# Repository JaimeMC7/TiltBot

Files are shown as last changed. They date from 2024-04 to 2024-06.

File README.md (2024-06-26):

# TiltBot
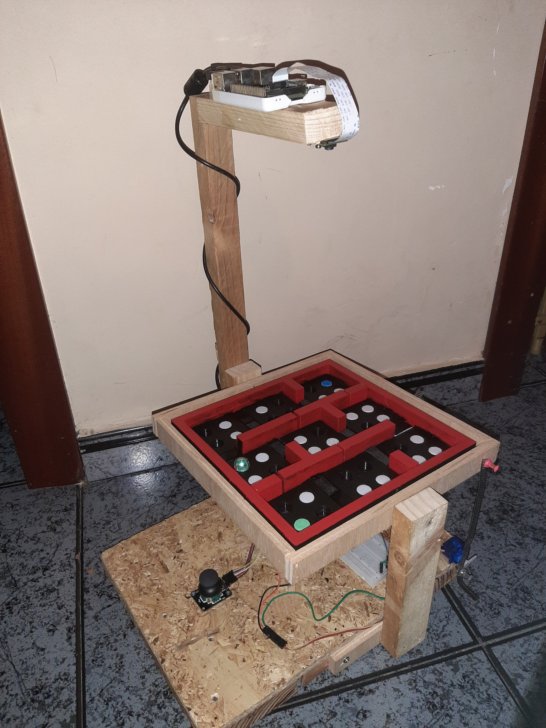
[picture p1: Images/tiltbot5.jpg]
TiltBot-image


# Authors
- David Fuentes Insa
- Sergio López Parejo
- Robert Pearson Ruiz
- Jaime Martínez Coca

## Index
- [Project description](#Project-description)
- [Structure](#Structure)
  - [Labyrinth platform](#Labyrinth-platform)
  - [Walls and plugs](#Walls-and-plugs)
- [Arquitecture](#Arquitecture)
  - [Action Module](#Action-Module)
    - [Action Hardware](#Action-Hardware)
    - [Action Software](#Action-Software)
  - [Vision Module](#Vision-Module)
    - [Vision Hardware](#Vision-Hardware)
    - [Vision Software](#Vision-Software)
    - [Limitations](#Vision-Limitations)
- [TO DOs](#TO-DOs)
- [References](#References)

## Project description
TiltBot is an entertainment device where you try to get a ball from one side of a maze to the opposite side, just by tilting it. Along the way, you'll need to dodge holes, or you'll have to start over!
Using it is simple: you can tilt the maze platform where the ball is located with a joystick.

If crossing the maze is too difficult, TiltBot has an extra feature. You can switch to an automatic mode, where AI will solve the maze, showing you one of the possible paths to the end. (For now, the algorithm is somewhat limited. See the Limitations section.)

Additionally, to increase the amount of fun, the maze format can be customized. You can open or close holes, as well as restructure the walls to choose your own difficulty.

## Structure
The structure is one of the most important parts of this project. To create a customizable maze, we had to come up with a structure that would allow us to rearrange where the walls that delimit the path of the maze should be, and the holes through which it should avoid falling. We designed the platform of our maze with holes where different pieces of walls fit and holes where plugs fit that allow the ball to pass over it. In addition to this, the structure has an exterior frame that will allow the platform to rotate on an axis. This has been achieved by means of a servomotor that will be attached to this frame by means of an elongated metal plate. As for the movement in the other axis of the inner platform, we have placed another servo attached to the bottom of the inner platform of the maze and joined to the outer frame by another plate. This allows us to obtain the desired movement in both axes.

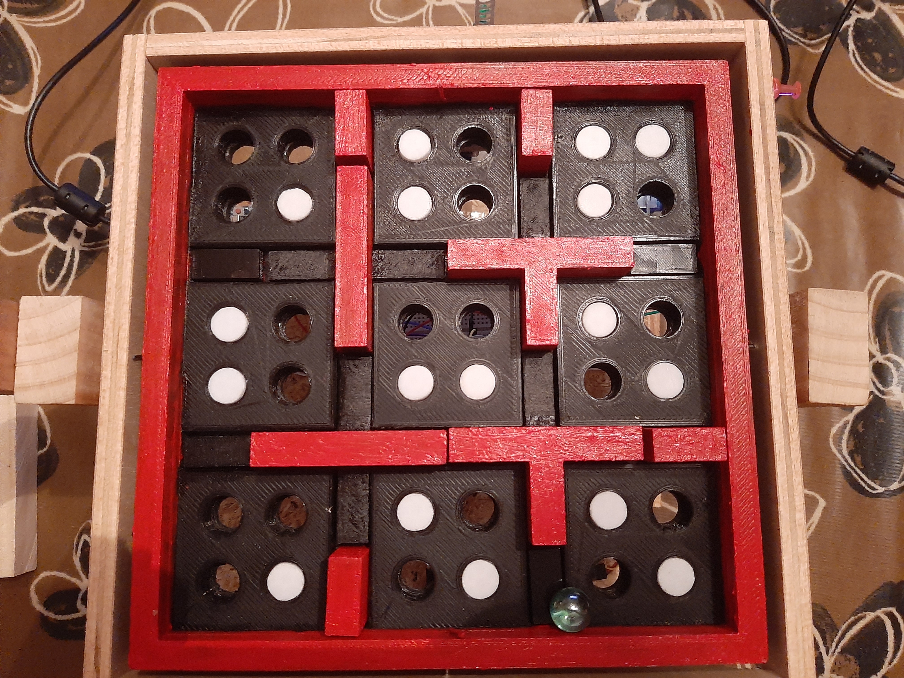
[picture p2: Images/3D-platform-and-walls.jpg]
3D-platform-and-walls


#### Labyrinth platform
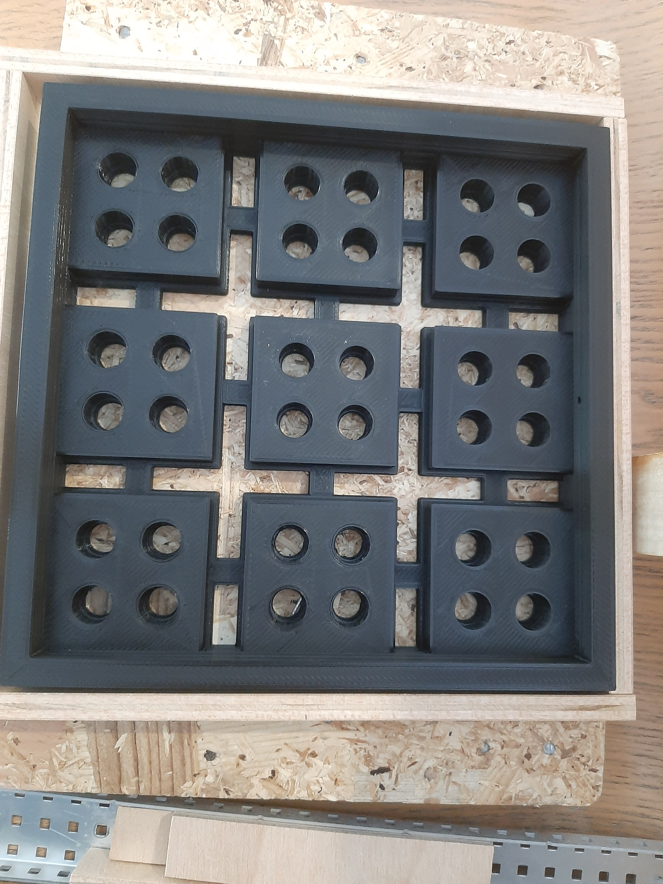
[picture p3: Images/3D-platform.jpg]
3D-platform

We made a platform that has nine main isles of floor. Among them, four central X-shaped holes remain in the center of the platform, and eight small holes are located on the exterior side. Also, each piece of the floor has four holes in it, that can be fitted with our plugs in order to make the maze either easier or harder.

#### Walls and plugs
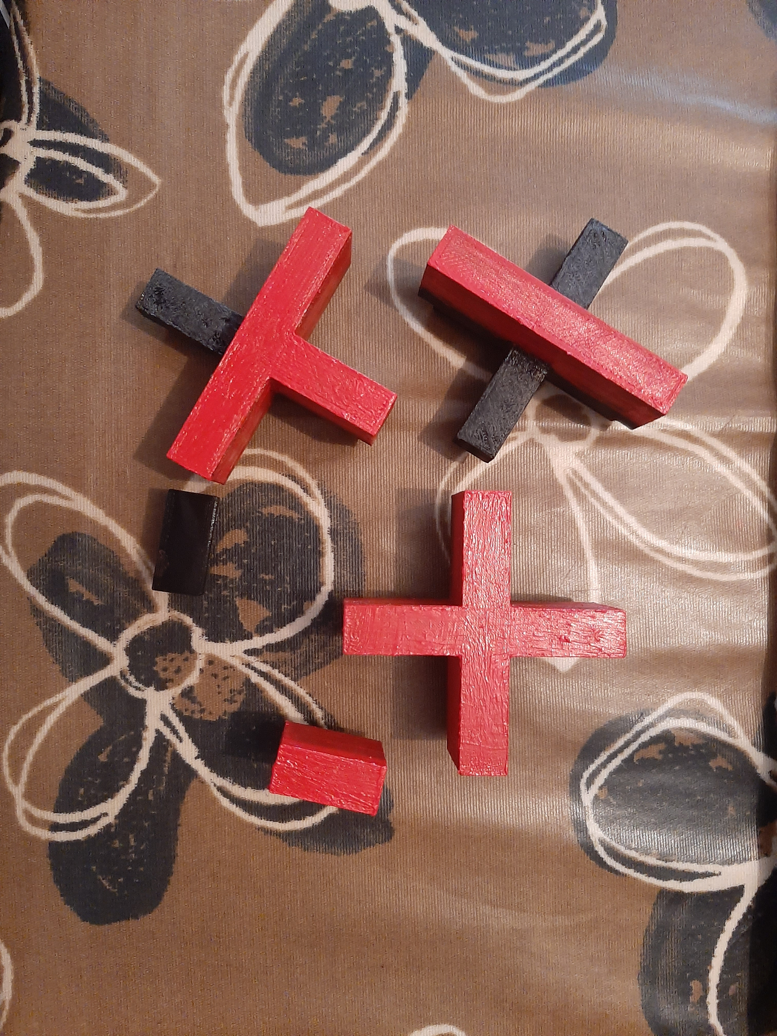
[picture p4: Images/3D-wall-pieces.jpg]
3D-wall-pieces

We have designed different types of central walls, combining parts at ground level that let us create very varied mazes. For the exterior walls, we only have two types, ground level and wall lavel. Regarding the plugs, they are all the same, and they are of such a height that allows the ball to pass over it effortlessly.

#### 

## Arquitecture
For the operation of TiltBot, we have divided its components into two interconnected modules.

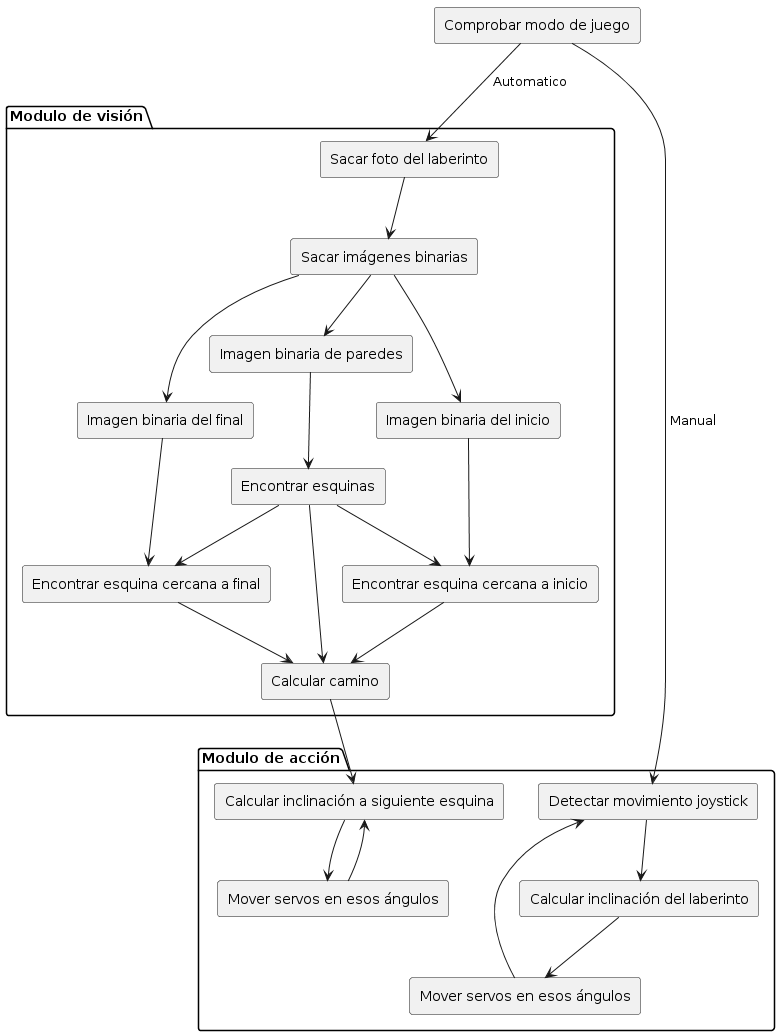
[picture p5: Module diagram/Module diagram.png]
Action-module-HW-components


### Action Module
This module is the one in charge of the actual movement of the labyrinth that allows the puzzle to be solved.

#### Action Hardware
In order to move the structure, we make use of two different servo motors, one for the outer layer, and the other for the inner layer. Each of this servos move in different directions, allowing the structure to tilt in any angle needed. For a deeper understanding check [Structure](#Structure).

To be able to control manually this servos we have also connected a joystick, which moves both motors acordingly to the direction and amount of preassure applied on it.

All of this is interconected by an Arduino UNO R3 module.

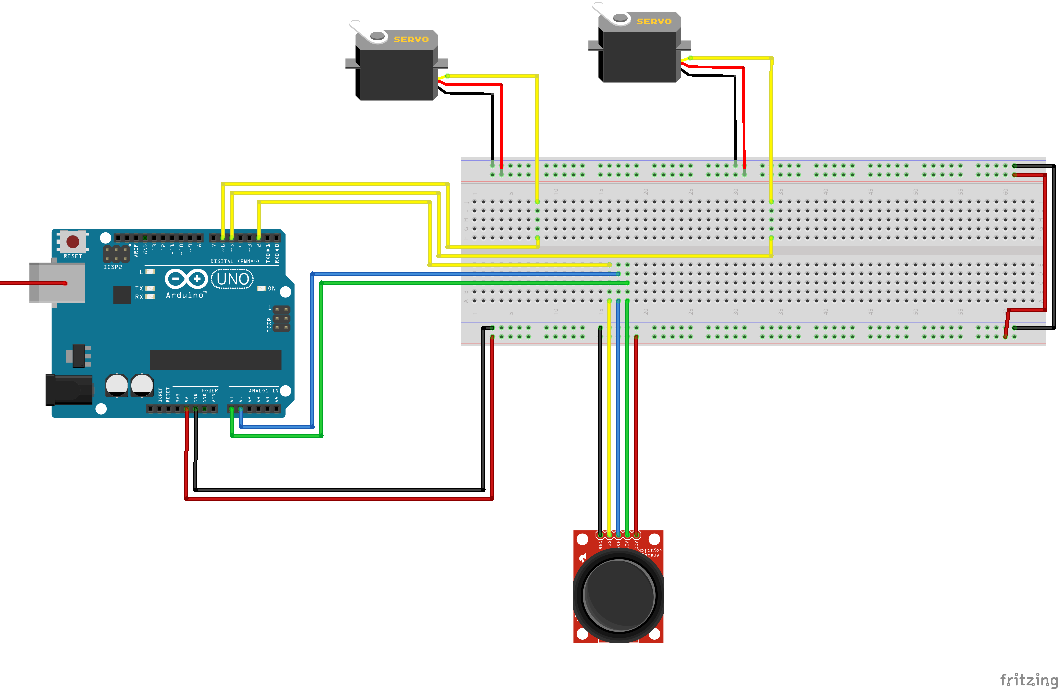
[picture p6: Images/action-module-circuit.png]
Action-module-HW-components


#### Action Software
To make the servo motors move, we have implemented some simple code in the Arduino.
This require the following libraries:
- Servo.h
- Keyboard.h
- ArduinoJson.h

The code workflow is:

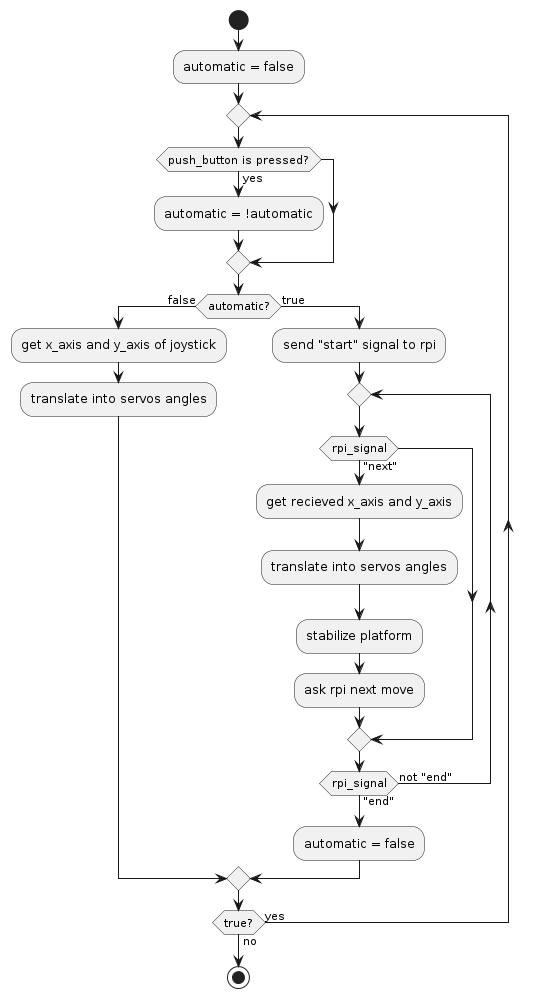
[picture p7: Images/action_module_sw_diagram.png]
action_module_sw_diagram


### Vision Module
The vision module is responsible for the automated maze-solving part. When requested, it will take a photograph of the maze from above and find a path from a starting point to an endpoint. It will then give instructions to the action module to try to move the ball along the path.

#### Vision Hardware
The hardware part is very simple. It consists of a Raspberry Pi 3B+ connected to a camera positioned above the center of the maze, and also connected to an Arduino UNO R3.

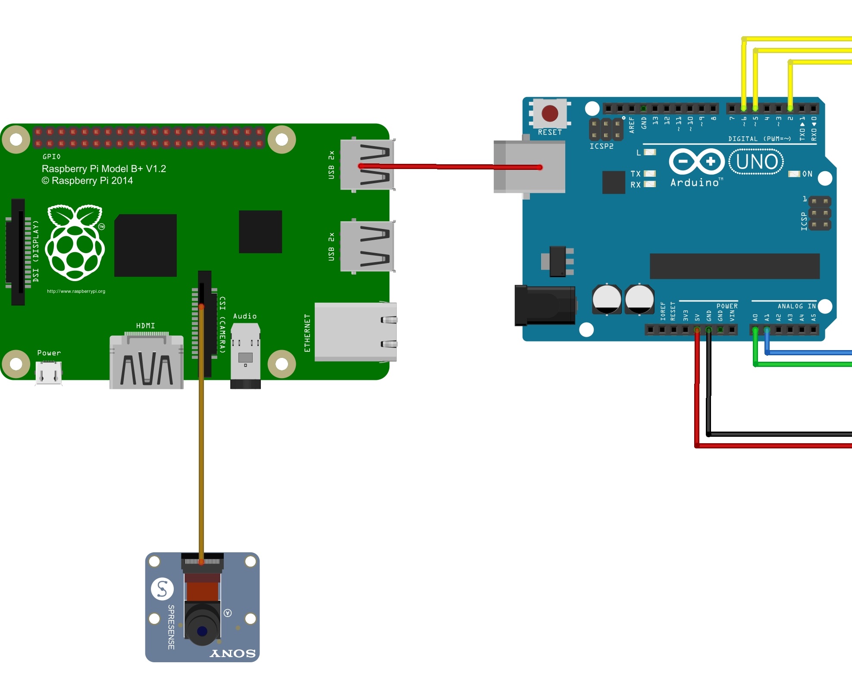
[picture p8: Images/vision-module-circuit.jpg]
Raspberry-and-cam


#### Vision Software
The software part is more complex.

*Dependencies*

To work with images, we use the OpenCV library and Numpy to handle the structures. 
Then, for the connection between the Raspberry Pi and the Arduino, we use the serial library along with the json library for sending information.

*Installation*

- pip install opencv
- pip install numpy
- pip install pyserial
- pip install json

The code waits for a start signal from the Arduino to begin the resolution algorithm. When it receives the signal, it takes a photograph of the maze, detects the walls, the starting point, and the ending point, and searches for a possible path that follows the walls.

<p>initial labyrinth photo</p>
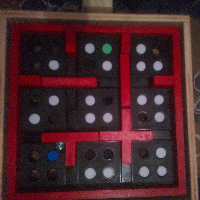
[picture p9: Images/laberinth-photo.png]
initial laberinth photo


<p>labyrinth separated by colors</p>
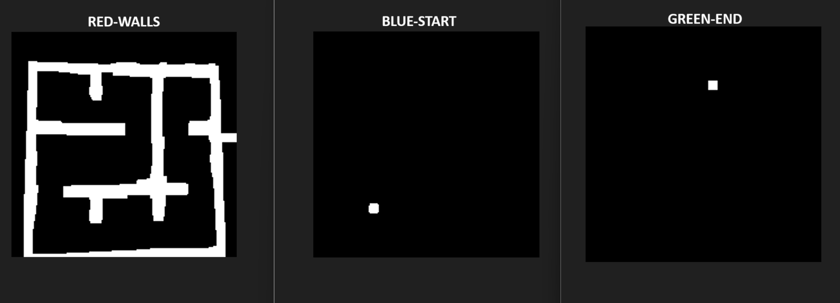
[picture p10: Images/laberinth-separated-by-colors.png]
color separation


<p>final labyrinth path</p>
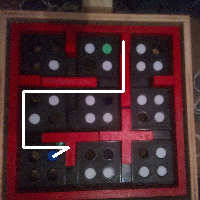
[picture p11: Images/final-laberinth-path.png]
final laberinth path


This path is calculated considering that when the maze is tilted, the ball will move to the nearest wall in that direction.

#### Vision Limitations
The pathfinding algorithm uses the walls to move the ball to the end. For this reason, there are some maze layouts that it is unable to solve, which are those where there is no way to access the final area through the walls. An example it cannot solve is the following.

The rest of the cases work correctly, at least on perfect images.

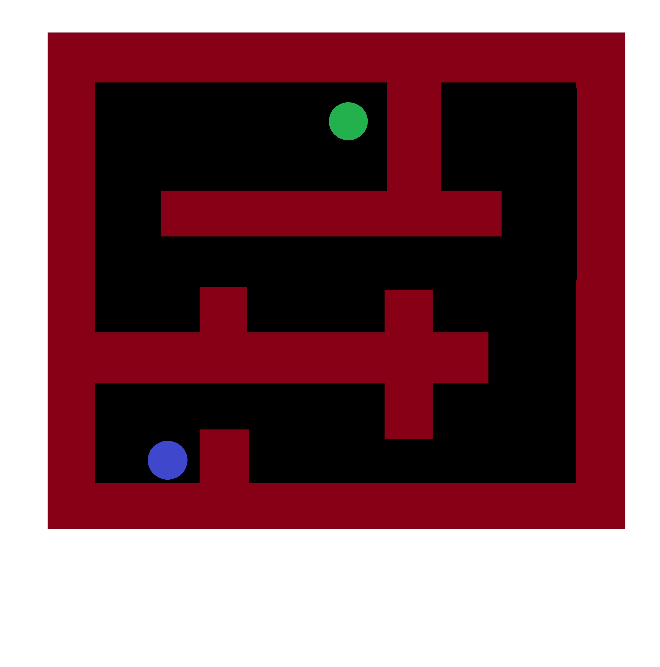
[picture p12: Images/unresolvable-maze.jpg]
Unresolvable maze


However, when applying the algorithm to real images, it does not work in 100% of the cases. Through testing, we have concluded that this is due to, among other things, imperfections in the materials/structure.

## TO DOs
- [x] Design and assembly of the structure.
- [x] Calibrate the movement ranges of the platform's servomotors.
  - [x] In the code.
  - [x] Phisically.
- [x] Vision Module.
  - [x] Differentiate obstacles, ball, and maze path using a camera.
  - [x] Basic algorithm to solve the maze.
  - [x] Improve the solving algorithm.
  - [x] Calibrate commands to move the ball in the correct direction.
- [x] Communication between the vision module and the action module.

## References
- Original idea for the project by Antonio Álvarez: https://www.youtube.com/watch?v=PMSr5L0SD24
- Tutorial - Usage of Joysticks with Arduino: https://programarfacil.com/blog/arduino-blog/joystick-con-arduino/
- Tutorial - Usage of Servos with Arduino: https://programarfacil.com/blog/arduino-blog/servomotor-con-arduino/
- Tutorial - Send data from Arduino to Raspberry (Serial connection): https://www.youtube.com/watch?v=-3swby4ryU4

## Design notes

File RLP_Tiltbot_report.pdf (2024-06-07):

RPL - Computer Engineering. UAB (Barcelona) 2023-2024

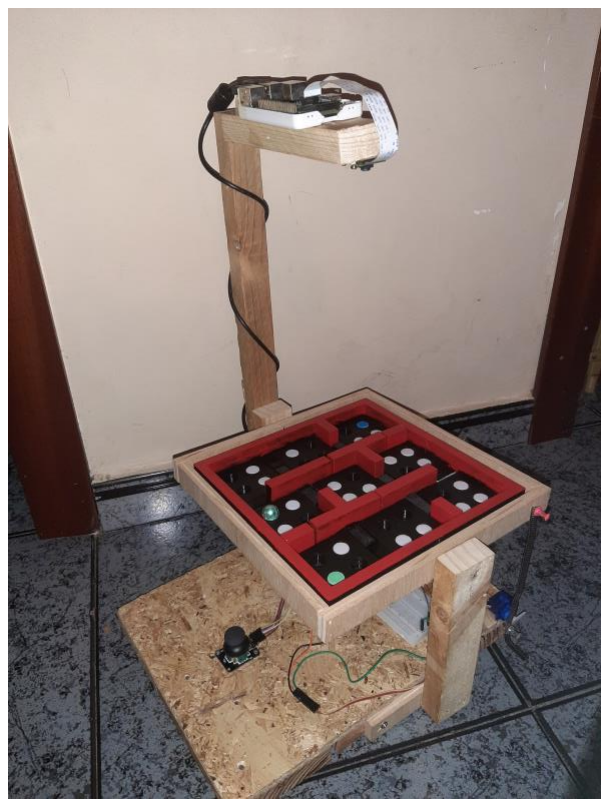
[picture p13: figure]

# TiltBot

Interactive maze-solving entertainment device.

FINAL SPRINT
DATE: 12 June 2024

Jaime Martinez Coca - 1634495 Robert Pearson Ruiz - 1630916 Sergio López Parejo - 1634093 David Fuentes Insa - 1637892

TiltBot

# Table of Contents

Final Sprint
Date: 12 June 2024
TiltBot | 1

# TiltBot

Interactive maze-solving entertainment device.

### Project description

TiltBot is an entertainment device where you try to get a ball from one side of a maze to the opposite side, just by tilting it. Along the way, you'll need to dodge holes, or you'll have to start over! Using it is simple: you can tilt the maze platform where the ball is located with a joystick.

If crossing the maze is too difficult, TiltBot has an extra feature. You can switch to an automatic mode, where AI will solve the maze, showing you one of the possible paths to the end. (For now, the algorithm is somewhat limited. See the Limitations section.)

Additionally, to increase the amount of fun, the maze format can be customized. You can open or close holes, as well as restructure the walls to choose your own difficulty.

### Electronic components

This is the list of the used components:

◼ Arduino UNO R3

◼ Raspberrypi 3B+

◼ Joystick

◼ x2 Microservo

◼ Camera Raspberrypi v2

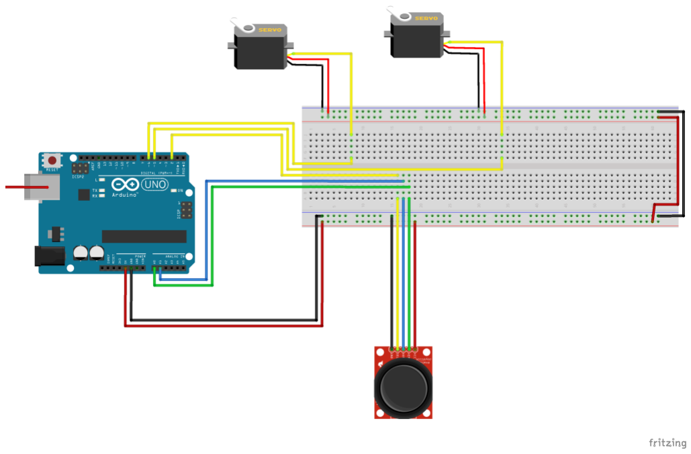
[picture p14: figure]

TiltBot | 2

### Action Module

This module is the one in charge of the actual movement of the labyrinth that allows the puzzle to be solved.

Action Hardware

In order to move the structure, we make use of two different servo motors, one for the outer layer, and the other for the inner layer. Each of these servos move in different directions, allowing the structure to tilt in any angle needed. For a deeper understanding check Structure.

To be able to control manually these servos we have also connected a joystick, which moves both motors accordingly to the direction and amount of pressure applied on it.

All of this is interconnected by an Arduino UNO R3 module.

❖ Servo_1 SEL is connected to digital pin 6 ❖ Servo_2 SEL is connected to digital pin 5 ❖ Joystick SEL is connected to digital pin 2 ❖ Joystick VER is connected to digital pin A0 ❖ Joystick HOR is connected to digital pin A1

Figure 1. Action module HW circuit.


TiltBot | 3

Action Software

To make the servo motors move, we have implemented some code in the Arduino.

The code is divided into two sections, one for manual
movement (using the joystick) and another for
automated movement using the Raspberry Pi.

To start, we initialize the game mode in manual mode and enter the main program loop.

In this main loop, we check if the joystick button has been pressed. If so, we switch modes (if we were in manual mode, we switch to automatic mode, and vice versa).

Then, if we are in manual mode, we simply read the tilt angles on the X and Y axes of the joystick and translate them into corresponding angles on the two servo motors.

If, on the other hand, we are in automatic mode, a signal is sent to the Raspberry Pi to indicate that we are starting the automated algorithm. Then, we enter an internal loop where the Arduino will wait for movements from the servo motors until receiving a completion message.

When it receives this completion message, it will exit the loop, return to manual mode, and go back to the main loop.

Figure 2. Action Module SW flux diagram.

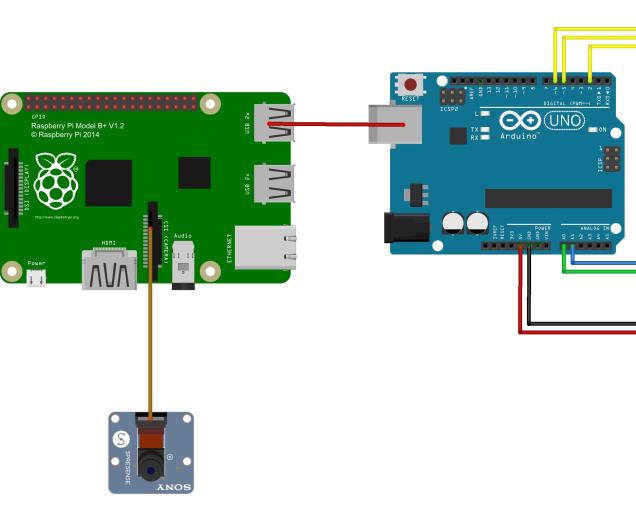
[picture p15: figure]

TiltBot | 4

### Vision Module

The vision module is responsible for the automated maze-solving part. The idea is to move the ball across the maze following the walls, so it does not fall into any holes.

When requested by the Action module, it will take a photograph of the maze from above and find a path from a starting point to an endpoint. It will then give instructions to the action module to try to move the ball along the path.

Vision Hardware

The hardware part is very simple. It consists of a Raspberry Pi 3B+ connected to a camera positioned above the center of the maze, and also connected to an Arduino UNO R3.

Figure 3. Vision Module HW.

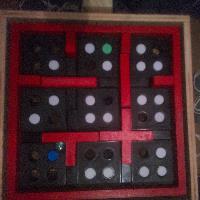
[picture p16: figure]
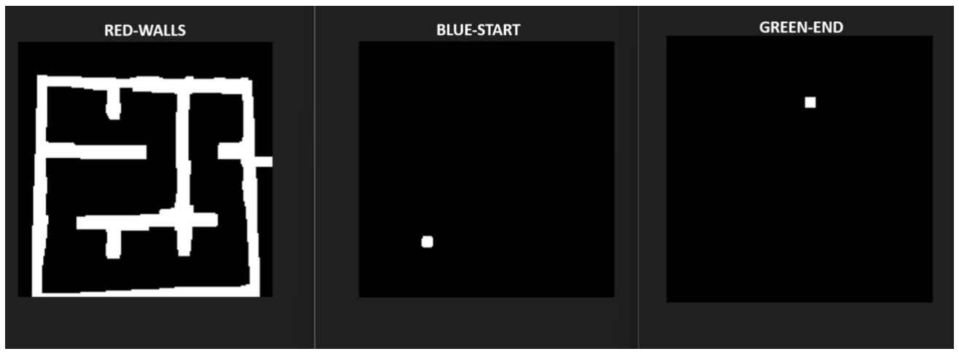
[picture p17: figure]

TiltBot | 5

Vision Software

The code waits for a start signal from the Arduino to begin the resolution algorithm. When it receives the signal, it takes a photograph of the maze. From this image the Raspberry detects the walls, the starting point, and the ending point using the color of the pieces to differentiate them.

Figure 5. Detected parts of the example.

Then, we find all the corners, and calculate which of those corners are closer to the start and end points.

Once we have these closer corners, we search for a path across the corners of the labyrinth.

In this search we must consider that we are moving a ball, so when we move it to a “internal” corner, it will continue moving until it collides with the next wall.

Figure 4. Initial photo of example.

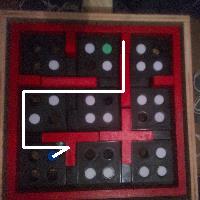
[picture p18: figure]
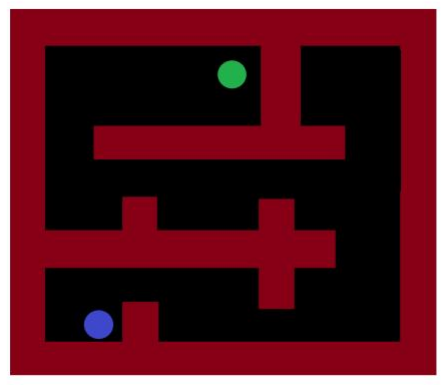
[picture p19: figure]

TiltBot | 6

If there is a valid path, then this is returned, and sends point by point the movements to the Arduino. From one point to the next one the Raspberry waits for the correct signal from the Arduino.

Vision Software Limitations

The pathfinding algorithm uses the walls to move the ball to the end. For this reason, there are some maze layouts that it is unable to solve, which are those where there is no way to access the final area through the walls. An example it cannot solve is the following.

The rest of the cases work correctly, at least on perfect images.

However, when applying the algorithm to real images, it does not work in 100% of the cases. Through testing, we have concluded that this is due to, among other things, imperfections in the materials/structure.

Figure 6. Valid path.

Figure 7. Unresolvable maze.

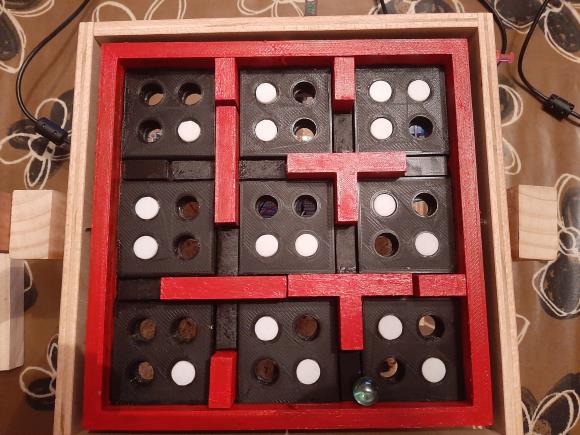
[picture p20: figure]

TiltBot | 7

### Structure

The structure is one of the most important parts of this project. To create a customizable maze, we had to come up with a structure that would allow us to rearrange where the walls that delimit the path of the maze should be, and the holes through which it should avoid falling. We designed the platform of our maze with holes where different pieces of walls fit and holes where plugs fit that allow the ball to pass over it. In addition to this, the structure has an exterior frame that will allow the platform to rotate on an axis. This has been achieved by means of a servomotor that will be attached to this frame by means of an elongated metal plate. As for the movement in the other axis of the inner platform, we have placed another servo attached to the bottom of the inner platform of the maze and joined to the outer frame by another plate. This allows us to obtain the desired movement in both axes.

Extra components and 3D pieces

◼ Labyrinth base

◼ Plugs

◼ x4 exterior walls

◼ x4 exterior floor pieces

◼ x2 cross shaped walls

◼ x2 T shaped walls

◼ x2 I shaped walls

Figure 8. Final platform sample.

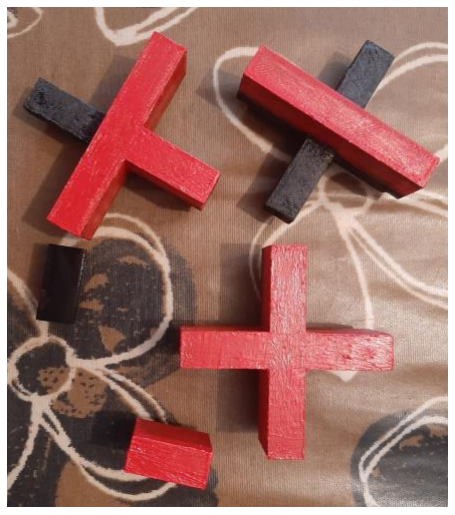
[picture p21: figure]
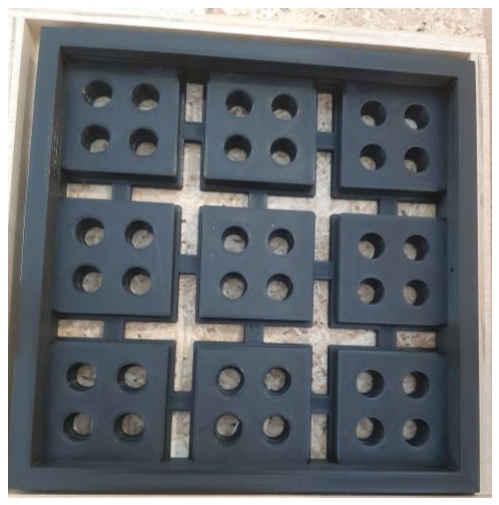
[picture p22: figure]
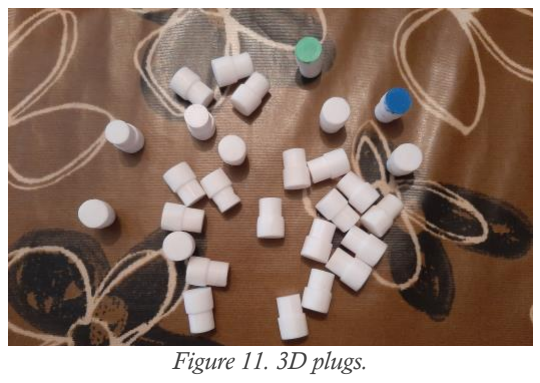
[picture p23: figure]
Figure 11. 3D plugs.

TiltBot | 8
- We made a platform that has nine main isles of floor. Among them, four central X-shaped holes remain in the center of the platform, and eight small holes are located on the exterior side. Also, each piece of the floor has four holes in it, that can be fitted with our plugs in order to make the maze either easier or harder.
- Regarding the plugs, they are all the same, and they are of such a height that allows the ball to pass over it effortlessly. These plugs allow us to change the location of the holes, as well as modifying the difficulty of the maze, increasing or decreasing the number of wholes through which the ball can fall through.
- All the different types of walls and floors are also made so that we can change the shape and paths of the maze. Each piece has either floor, wall or both depending on the piece. On the one hand the floor parts are only as tall as the labyrinth base, so that the ball can go over these pieces without any struggle. On the other hand, the wall parts are made taller, so that the ball can not go pass them, giving the shape of the path that it needs to do in order to get to the end.
Figure 9. 3D platform piece. | Figure 10. 3D wall pieces.

TiltBot | 9

### Foreseen risks and contingency plan

Risk # | Description | Probability (High/ Medium/ Low) | Impact (High/ Medium/ Low) | Contingency plan
1 | Computer vision does not always solve the maze (it finds a path, but the ball deviates / it does not find a path | High | Medium | Perfecting the materials with millimetric precision and improving the image quality.

Table 1. Foreseen risks and contingency plans.

TiltBot | 10

# References

This project has been inspired by the following Internet projects:

Original idea for the project by Antonio Álvarez: https://www.youtube.com/watch?v=PMSr5L0SD24

Tutorial - Usage of Joysticks with Arduino: https://programarfacil.com/blog/arduino-blog/joystick-con-arduino/ (https://programarfacil.com/blog/arduino-blog/joystick-con-arduino/)

Tutorial - Usage of Servos with Arduino: https://programarfacil.com/blog/arduino-blog/servomotor-con-arduino/ (https://programarfacil.com/blog/arduino-blog/servomotor-con-arduino/)

Tutorial - Send data from Arduino to Raspberry (Serial connection): https://www.youtube.com/watch?v=-3swby4ryU4

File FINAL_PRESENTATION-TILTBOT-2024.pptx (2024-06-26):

## TILTBOT

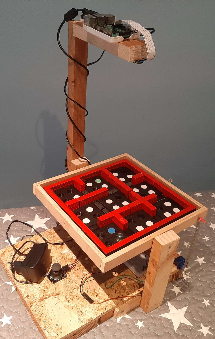
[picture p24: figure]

El robot TiltBot permite controlar una bola a través de un laberinto personalizable mediante un joystick.
¡También puede resolverse por sí mismo!

Robòtica, llenguatge I planificació – Enginyeria informàtica - uab

Jaime Martinez Coca - 1634495
Robert Pearson Ruiz - 1630916
Sergio López Parejo - 1634093
David Fuentes Insa - 1637892

## 1. Arquitectura hardware y software

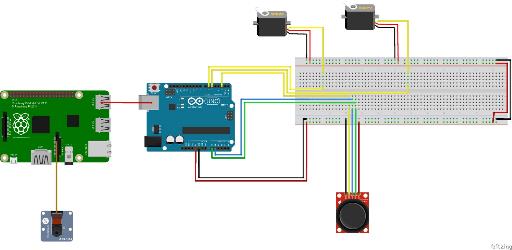
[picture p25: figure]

## 2. Algorítmica

Cálculo de camino
1. Tomar imagen
2. Procesamiento
  1. Imagen binaria de paredes
  2. Imagen binaria del inicio
  3. Imagen binaria del final
3. Encontrar esquinas
4. Esquinas más cercanas a inicio y final
5. Búsqueda de camino siguiendo esquinas

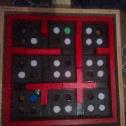
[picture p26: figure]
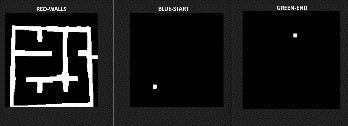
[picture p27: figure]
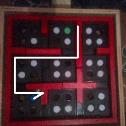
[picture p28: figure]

## FOTOS, VIDEO y Git

https://www.youtube.com/watch?v=3a_RwzYct-s

https://github.com/JaimeMC7/TiltBot

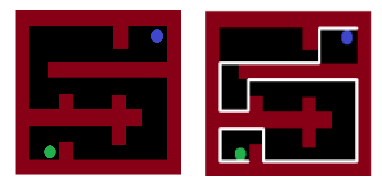
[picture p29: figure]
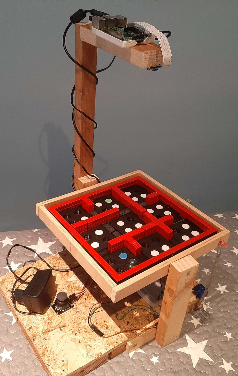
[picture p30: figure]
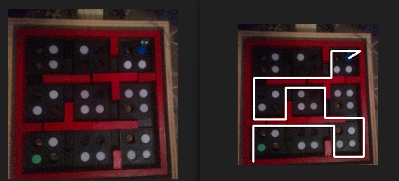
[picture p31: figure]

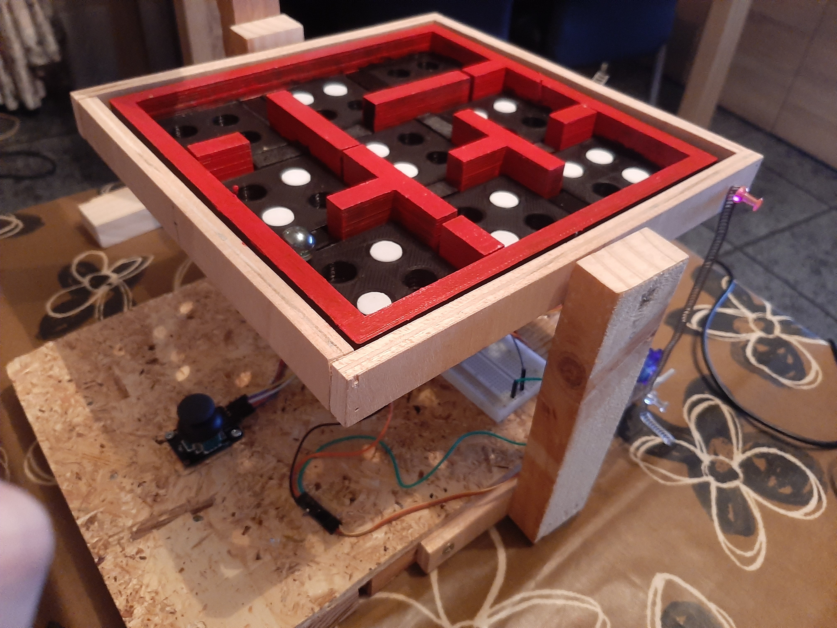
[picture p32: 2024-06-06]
Images/tiltbot2.jpg

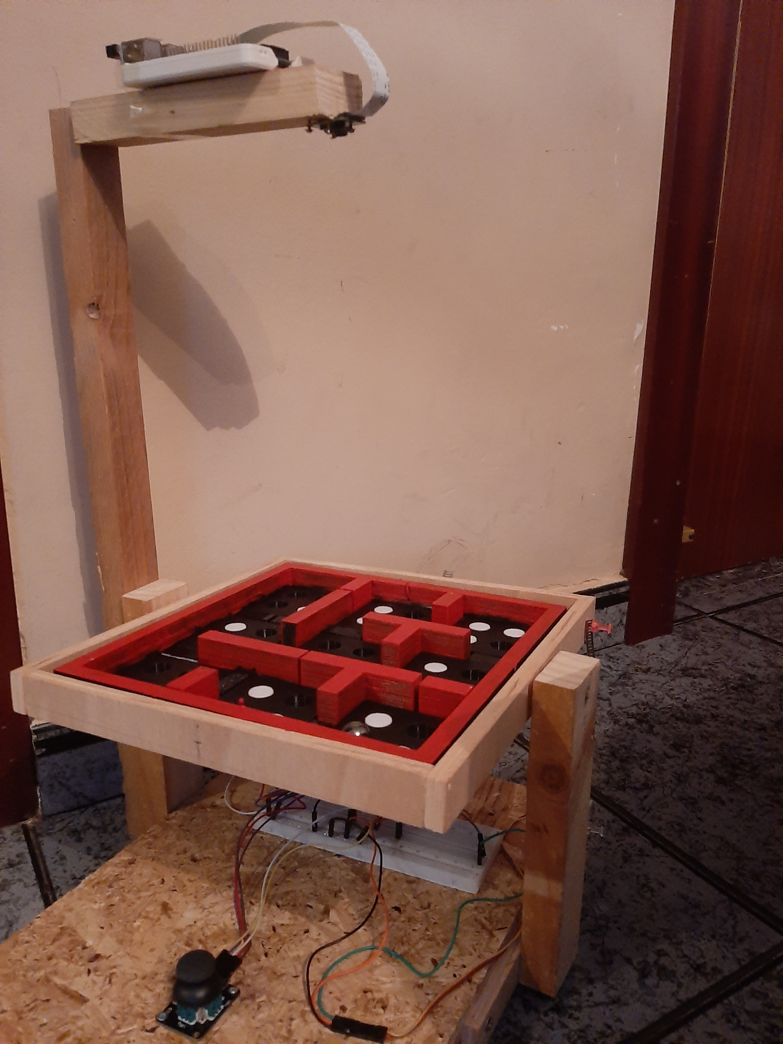
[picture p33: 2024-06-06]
Images/tiltbot1.jpg

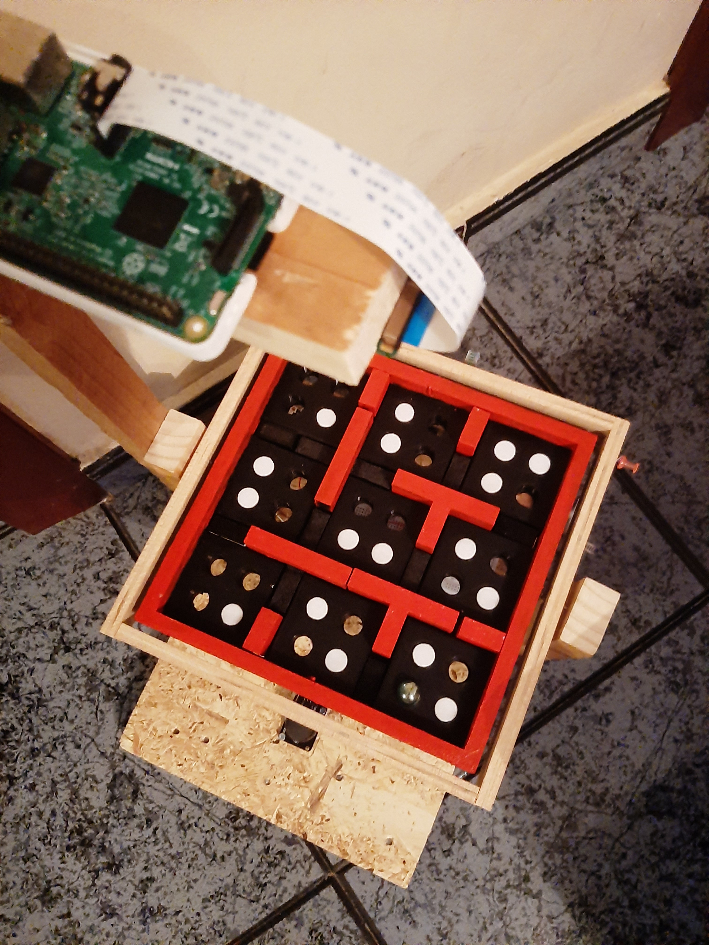
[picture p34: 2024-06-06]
Images/tiltbot4.jpg

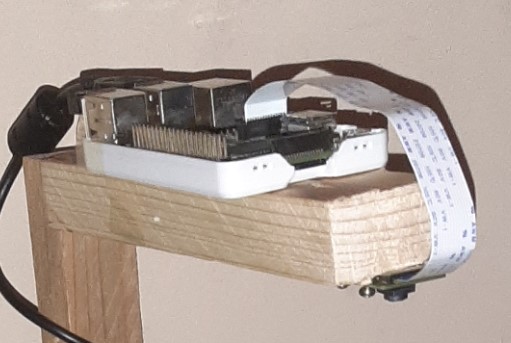
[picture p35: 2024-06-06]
Images/vision-module-raspberry-and-cam.jpg

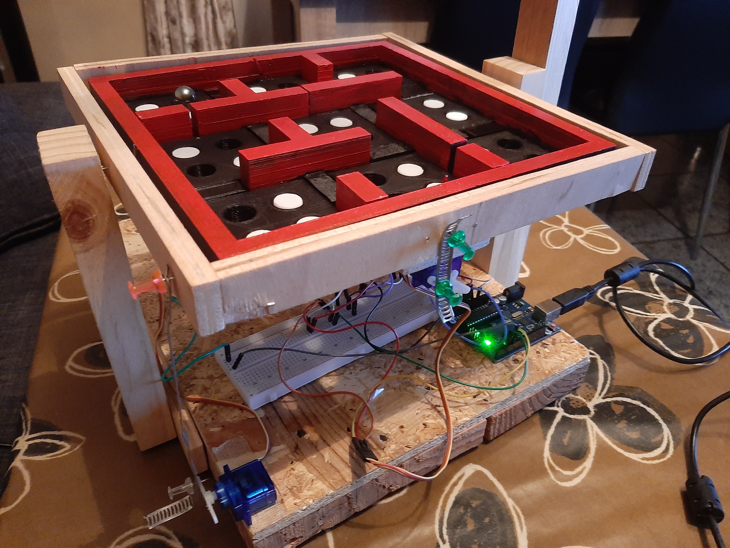
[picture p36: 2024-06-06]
Images/tiltbot3.jpg

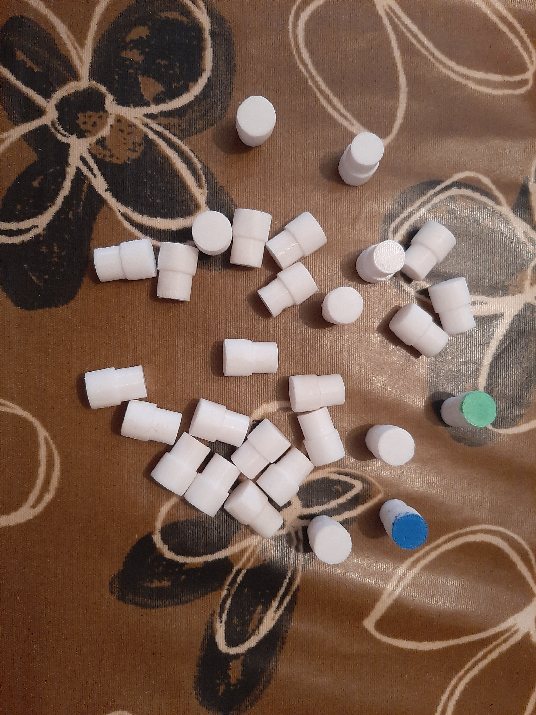
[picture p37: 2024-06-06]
Images/3D-plugs.jpg

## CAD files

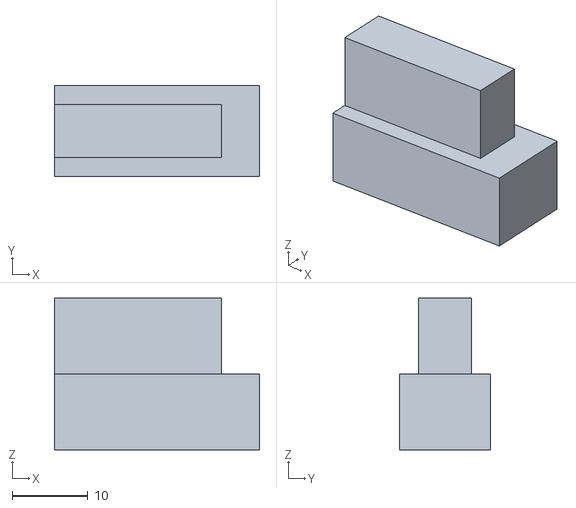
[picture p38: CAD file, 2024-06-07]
3D models/lateralfloorx4.stl
27.0 x 12.0 x 20.0

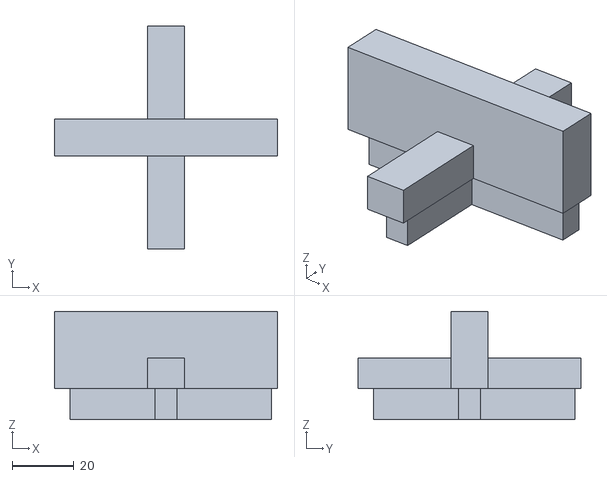
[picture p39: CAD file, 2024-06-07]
3D models/middlewallAx2.stl
72.0 x 72.0 x 35.0

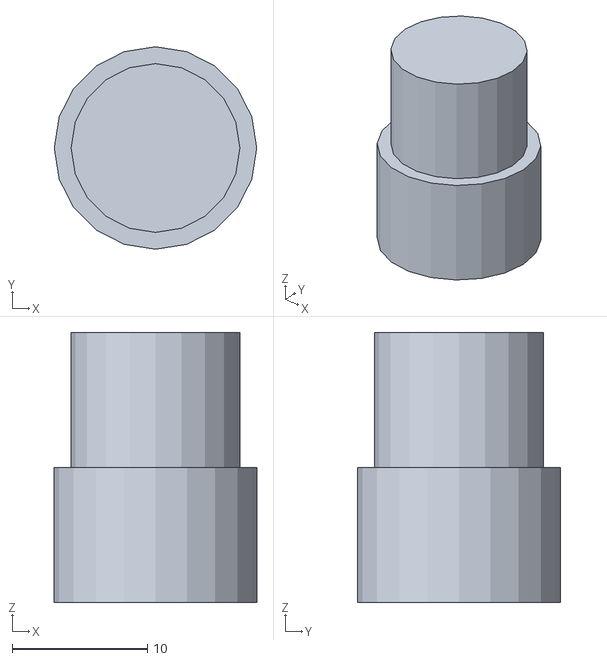
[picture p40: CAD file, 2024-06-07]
3D models/top.stl
15.0 x 15.0 x 20.0

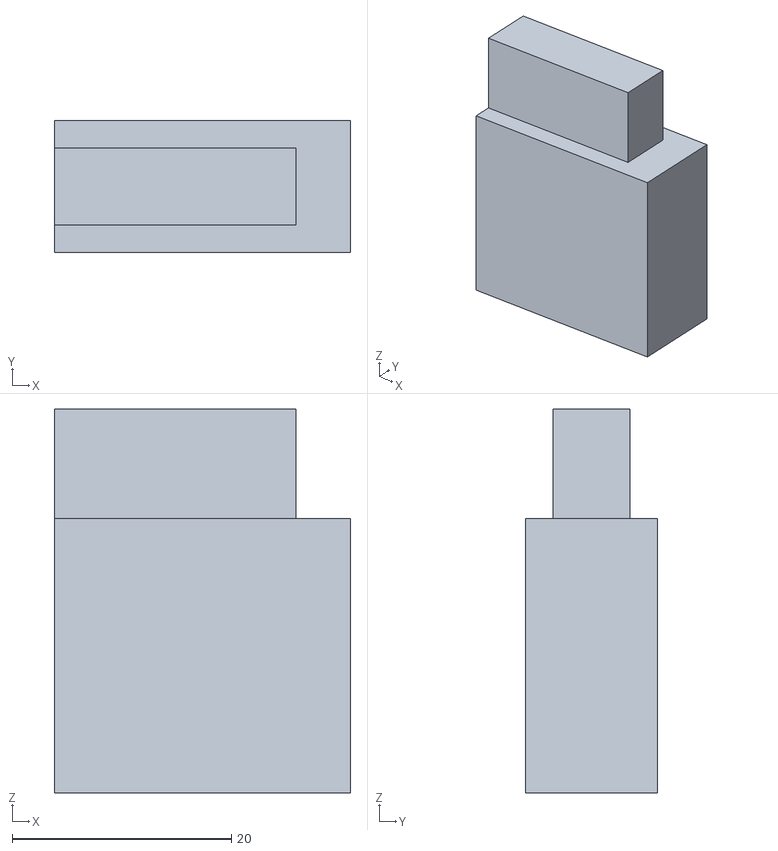
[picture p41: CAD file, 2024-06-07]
3D models/lateralwallx4.stl
27.0 x 12.0 x 35.0

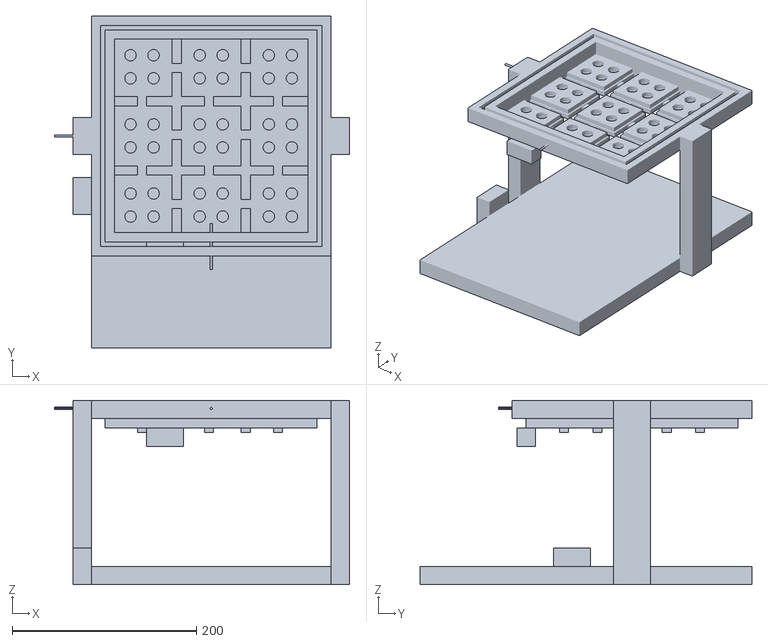
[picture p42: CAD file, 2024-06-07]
3D models/sketch.stl
320.0 x 360.0 x 200.0

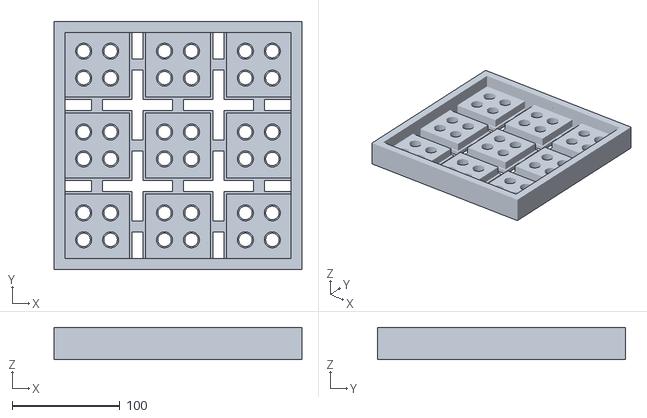
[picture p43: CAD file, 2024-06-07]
3D models/base_x1.stl
230.0 x 230.0 x 30.0

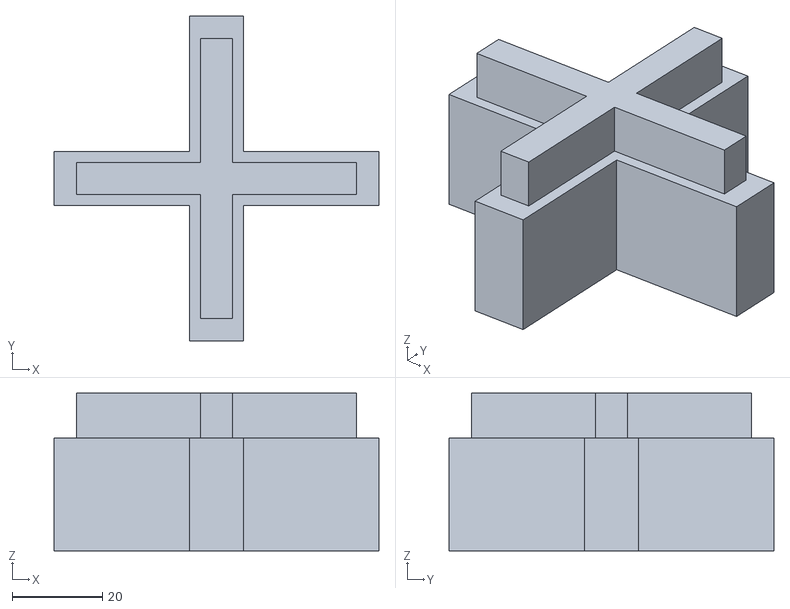
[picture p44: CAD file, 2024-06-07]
3D models/middlewallBx2.stl
72.0 x 72.0 x 35.0

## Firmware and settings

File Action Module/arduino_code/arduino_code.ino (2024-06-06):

#define PIN_VRx A1
#define PIN_VRy A0
#define PIN_SW 2
 
// Includes y declaraciones de servo motores
#define PIN_SERVO_EXT 6
#define PIN_SERVO_INT 5

#include <Servo.h>
#include <Keyboard.h>

// Include para conexion serial con Raspberry Pi
#include <ArduinoJson.h>

Servo servoExterior;
Servo servoInterior;

// Valores centrales servomotores
int central_external_servo = 129;
int central_internal_servo = 121;


// Modo de juego
bool automatic = false;




// Enviar senal en serie
//
// Mensajes enviados:
//   200 --> empezar proceso automatico
//   300 --> siguiente punto
//   400 --> cancelar/acabar proceso
//



void serial_out(int value){

  //StaticJsonDocument<200> jsonDoc;
  //jsonDoc["value"] = value;
  //serializeJson(jsonDoc, Serial);

  Serial.print(value);
  Serial.println();

}


// Girar servomotores
void move(int x_ang, int y_ang){
  servoExterior.write(x_ang);
  servoInterior.write(y_ang);
}

// Todo el calculo automatico y comunicacion
void automatic_move(){

  // Decimos que empezamos el proceso
  serial_out(200);

  while (automatic){

    check_change_button();

    if (Serial.available() > 0) {

      String receivedString = Serial.readStringUntil('\n');
      StaticJsonDocument<200> jsonDoc;
      DeserializationError error = deserializeJson(jsonDoc, receivedString);
      
      if (!error) {
        int state = jsonDoc["state"];

        if (state == 400){ 
          automatic = false;
          break;
        } 
        // else: ended == 200
        int x_value = jsonDoc["x_value"];
        int y_value = jsonDoc["y_value"];

        //Serial.print("Received values: {x_value: ");
        //Serial.print(x_value);
        //Serial.print(", y_value: "); 
        //Serial.print(y_value);
        //Serial.println();

        int x_ang = map( x_value, -1, 1, 45, 180 );
        int y_ang = map( y_value, -1, 1, 140, 100 );

        // Movemos
        move(x_ang, y_ang);
        delay(2000);

        // Recolocamos poco a poco
        int step = 1;
        if (y_ang > central_internal_servo){
          step = -1;
        } 

        x_value = 0;
        y_value = 0; 
        x_ang = map( x_value, -1, 1, 45, 180 );

        y_ang = y_ang + step;
        while (y_ang != central_internal_servo){
          move(x_ang, y_ang);
          y_ang = y_ang + step;
          delay(200);
        }
        
        delay(500);

        // Decimos que continuamos
        serial_out(300);
      }
      else {

        //Serial.print("error");
      }

      

    }

  }

}


void manual_move(){
  // Posiciones del joystick
  int x = analogRead(PIN_VRx);
  int y = analogRead(PIN_VRy);
  // Mapeo de los valores a grados (0-180)

  int x_ang = map( x, 0, 1023, 45, 180 );

  int y_ang = map( y, 0, 512, 138, 119 );
  if (y > 512){
     y_ang = map( y, 512, 1023, 119, 110 );
  }

  
  //y_ang = 100; //120 centro; //140

  //Print de los valores en monitor serie
  
  /*
  Serial.print( "Joystick x value:" );
  Serial.print(x);
  Serial.print("  ");

  Serial.print( "Joystick y value:" );
  Serial.print(y);
  */
  
  //Desplazar servomotores
  move(x_ang, y_ang);
	
  // servoExterior.write(x_ang);
  // servoInterior.write(y_ang);

}



// Comprobamos si se ha pulsado el joystick
//
// Si se ha pulsado, cambiamos a modo automatico
void check_change_button(){

  int change = digitalRead(PIN_SW);

  // 0 pulsado -- 1 no pulsado
  /*
  Serial.print( " SW (Boton joystick):");
  Serial.print( change );
  Serial.println();
  */

  // Queremos cambiar
  if (change == 0){

    // Si estabamos en automatico, mandamos mensaje de cancelacion
    if (automatic){
      serial_out(400);
      digitalWrite(LED_BUILTIN, LOW); // Apagamos el LED

      /*
      Serial.print( "====================================");
      Serial.print( "Cancelando. Volviendo a modo manual.");
      Serial.print( "====================================");
      */
      automatic = false;
    }
    else{
      /*
      Serial.print( "============================");
      Serial.print( "Entrando a modo automatico.");
      Serial.print( "============================");
      */

      automatic = true;
    }

    //automatic = !automatic;


    delay(1000);
  }
}



/////////////////////////////////////
/////// FUNCIONES PRINCIPALES ///////
/////////////////////////////////////

// Inicializaciones
void setup(){
  
  // inicializar monitor serie a 9600 baudios
  Serial.begin(9600);
  analogReference(DEFAULT);

  //  Configuramos pin del pulsador del joystick como entrada con pullup
  pinMode(PIN_SW, INPUT_PULLUP);
  pinMode(PIN_VRx, INPUT); // Configurar el pin como entrada
  pinMode(PIN_VRx, INPUT); // Configurar el pin como entrada

  pinMode(LED_BUILTIN, OUTPUT);


	//Enlazamos el motor exterior al pin PIN_SERVO_EXT
	servoExterior.attach(PIN_SERVO_EXT);
  servoExterior.write(central_external_servo);

	//Enlazamos el motor interior al pin PIN_SERVO_INT
	servoInterior.attach(PIN_SERVO_INT);
  servoInterior.write(central_internal_servo);
}


// Bucle principal
void loop(){

  
  if (!automatic){
    //serial_out(200);
    //Serial.print( "manual");
    //Serial.println();
    manual_move();
  }
  else {

    automatic_move();

    //Serial.print( "=========================");
    //Serial.print( "Volviendo a modo manual.");
    //Serial.print( "=========================");

    //automatic = false;
    //serial_out(400);
    digitalWrite(LED_BUILTIN, HIGH); // Apagamos el LED
  }

  check_change_button();
  //Serial.print("Automatic= ");
  //Serial.print(automatic);
  //Serial.println();


  //Esperar 1/4 de segundo (en milisegundos)
	//delay(1000);
  

}

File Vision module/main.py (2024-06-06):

import serial #pip install pyserial
import json
import sys

import subprocess

import vision as v


ser = serial.Serial('/dev/serial/by-id/usb-Arduino__www.arduino.cc__0043_7563031393635160B231-if00', 9600, timeout=1)


def send_data(state, x, y):
    data = {"state": state, "x_value": x, "y_value": y}
    json_data = json.dumps(data)
    ser.write((json_data + '\n').encode('utf-8'))  # Asegúrate de enviar un salto de línea


def calc_direction(p1, p2):
    y = -1
    if p1[0] > p2[0]:
      y = 1
    elif p1[0] == p2[0]:
      y = 0
    
    x = -1
    if p1[1] > p2[1]:
       x = 1
    elif p1[1] == p2[1]:
       x = 0
       
    return x, y 


def send_error():
    error_msg = [[-1,-1], [-1, 1], [1,1], [1,-1]]
    
    
    act_point = error_msg[0]
    send_data(200, act_point[0], act_point[1])
    
    index = 1
    
    while True:
        if ser.in_waiting > 0:
            line = ser.readline().decode("latin1").rstrip()
            print(line)

            try:
                #jsonObj = json.loads(line)
                pot = line
                print("value: ", pot)

                if pot == "300":
                    act_point = error_msg[index]
                    send_data(200, act_point[0], act_point[1])
                    
                    index += 1
                    
                    if index >= len(error_msg):
                      send_data(400, -1, -1)
                      break
                
                elif pot == "400": #fin
                    break
                

                ser.reset_input_buffer()
            except:
                print("Error")


def laberinth_algorithm():
    command = ["rpicam-jpeg", "-o", "/home/sergio/Vision_module/imagenes/originales/prueba.jpg", "-n"]
    try:
        subprocess.run(command, check=True)
        print("Imagen capturada exitosamente")
    except subprocess.CalledProcessError as e:
        print(f"Error al capturar la imagen: {e}")
    
    # Calcular el cami del laberint
    print("entro")
    path = v.main()
    print(path)
    
    # Si no se ha encontrado un camino, damos una vuelta
    if len(path) == 0:
        send_error()
        return
        

    act_point = path[0]
    next_point = path[1]
    
    
    x, y = calc_direction(act_point, next_point)
    send_data(200, x, y)
    
    act_point = next_point
    
    index = 2
    
    while True:
        if ser.in_waiting > 0:
            line = ser.readline().decode("latin1").rstrip()
            print(line)

            try:
                #jsonObj = json.loads(line)
                pot = line
                print("value: ", pot)

                if pot == "300":
                    next_point = path[index]
                    x, y = calc_direction(act_point, next_point)
                    send_data(200, x, y)
                    
                    act_point = next_point
                    index += 1
                    
                    if index >= len(path):
                      send_data(400, -1, -1)
                      break
                
                elif pot == "400": #fin
                    break
                

                ser.reset_input_buffer()
            except:
                print("Error")
    
        
        
        





def main():


    
    # Espera de una señal en serie
    while True:
        if ser.in_waiting > 0:
            line = ser.readline().decode("latin1").rstrip()
            print(line)

            try:
                #jsonObj = json.loads(line)
                pot = line
                print("value: ", pot)

                if pot == "200":
                    laberinth_algorithm()
                    print("Valor: ", pot)
                elif pot == "400": #fin
                    print("valor: ", pot)
                

                ser.reset_input_buffer()
            except:
                print("Errorrr")
    




if __name__ == "__main__":
    main()

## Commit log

2024-04-24 Added Action Module circuit v.1.0
    [Action Module circuit v1.fzz]
2024-04-24 Replaced circuit v.1.0. image for better quality
2024-05-22 Added first version arduino code of Action Module
2024-06-06 3D Models added
    [base_x1.stl, lateralfloorx4.stl, lateralwallx4.stl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]
